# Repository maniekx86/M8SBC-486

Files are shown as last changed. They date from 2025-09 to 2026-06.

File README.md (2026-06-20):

# M8SBC-486

All the sources (Schematics, PCB, VHDL, BIOS sources) for the M8SBC-486. 

This project is a 486 Homebrew computer, with some efforts to make it kinda PC compatible. See [my page about it](https://maniek86.xyz/projects/m8sbc_486.php).

soldered board

## Specs:

- 150*150mm 4 layer PCB
- PGA-168 socket for 5V 486 CPUs.
- Xilinx Spartan II XC2S100 FPGA as "chipset". Codename "Hamster 1"
- 4MB SRAM, (8*HM628512)
- 256KB of ROM (W29C020 or 39SF020A) (224 KB accessible)
- 8254 Programmable Interval Timer
- 8259 Programmable Interrupt Controller
- Two 16-bit ISA slots
- 8042 compatible PS/2 keyboard controller. Implemented in the FPGA
- Simple CMOS RTC and CMOS storage. Implemented in the FPGA too
- ATMega128 as reset circuit handler, nonvolatile CMOS storage and bitstream loader.

The FSB frequency is currently set to a fixed 24 MHz (DX2 CPUs run then at 48 MHz), but this can be changed by uncommenting/commenting lines in the FPGA source.

Secondary PIC and DMA are missing, so the compatibility is not full. The missing DMA especially breaks support for sound cards.

## Current progress:

The hardware and FPGA are mostly done. BIOS is capable of booting DOS. There are a few issues & bugs, but they are being slowly fixed.

Among the most impressive things the board (as time of writing: 20/06/2026) is capable of:

- Running Linux 2.2.26 ([using custom bootloader](https://github.com/maniekx86/linux_m8sbc_boot)) and Linux 4.4.302 (documentation is coming soon)

- Running MS-DOS and FreeDOS: The software compatibility is mixed. Some software hangs the system, throws exceptions, but some run fine. Most notable are: Second Reality demo (no sound), Prince of Persia, Wolfenstein 3D, Fasttracker II (PC speaker works in one mode, LPT DAC works okay), 3DBench 1.0c, CACHECHK. For more software checks and detailed information, see the compatibility table on the [project's website](https://maniek86.xyz/projects/m8sbc_486.php).

- Running DOOM ([FastDOOM](https://github.com/viti95/FastDoom) running on FreeDOS 1.4)

## Hardware diagram

Hardware diagram

<hr>

## Special thanks to [PCBWay](https://www.pcbway.com)!

[](https://www.pcbway.com)

Special thanks to PCBWay for sponsoring PCBs for this project! Their sponsorship was a huge help and enabled me to make progress with this project. PCBWay is a well-known PCB prototyping and manufacturing service, providing high-quality boards and excellent customer support. I have worked with their boards in the past and can say that they are of great quality. I easily placed an order for PCBs on their platform for this project without any problems. The sponsorship also included a free quick delivery option. If you’re looking for reliable PCB prototyping and manufacturing services, I highly recommend [checking them](https://www.pcbway.com).

# Folders

## pcb/

Schematic and PCB design for this homebrew computer. Board is 150mm*150mm with 4 layers. (Placement of the screw holes is not compliant with any standard)

## chipset/

Sources for the "Hamster 1" chipset. FPGA used is XC2S100 (Xilinx Spartan II). Compile with Xilinx ISE 10.1

## avr/

Sources for AVR ATMega128:

Small AVR firmware that configures the FPGA from on-chip flash at power-up and manages system reset for the M8SBC-486 project

## bios/

M8SBC-486 SeaPig BIOS

Based on this project: [b-dmitry1/BIOS](https://github.com/b-dmitry1/BIOS)

## Disclaimer

This project is essentially my hobby, as I like retro, electronics, digital circuits and low-level programming. I never expected this computer to run DOS in the first place. I consider it pretty much experimental and made to research the workings of older x86 chips. I am pretty sure that this work could be used to build something more robust and stable or even to develop fully custom-made boards for other x86 CPUs. It took me a lot of time, but I don't regret it. There are still many issues, but it's heartwarming that I can get so much existing software to work. And, thanks to everyone for support!

## Acknowledgements

Special thanks to: TheRetroWeb community, [b-dmitry1](https://github.com/b-dmitry1) and [PCBWay](https://pcbway.com/)

## More images

PCB bottom
3d render back
pcb view

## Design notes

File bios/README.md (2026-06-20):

# M8SBC-486 SeaPig BIOS

Minimal BIOS for M8SBC-486 that is capable of booting various operating systems such as MS-DOS, FreeDOS or Linux. 

Current version: A2.02

See docs/ for more technical information and release history.

## Building

Requirements: `make`, `nasm`, `dd`, `i686-linux-gnu-gcc`, `python3` (with Pillow installed, required for boot logo)

To build, clone repository and run `make` in this directory. Ready to flash image will be at `out/m8sbc_flash.bin`

## Improvements

- Fancy POST screen
- LBA support (read)
- Hard drive detection
- BIOS setup
- Extended memory test
- Compatibility fixes
- POST codes (see docs/)
- More complete keyboard implementation

## Issues / TODOs

- No LBA write support
- Compact flash cards get randomly corrupted (unsure if it's a hardware or BIOS issue).

## Original README

### x86 embedded BIOS R3

Very compact (less than 8KB of ROM space) x86 BIOS for embedded systems, FPGA, and emulators.

### Implemented functions and features

* Minimal initialization
* Minimal functionality ISRs 10h-1Ah
* Lower memory test with continuous mode to help debugging FPGA SDRAM controller
* Very compact Video BIOS
* Minimal SVGA functionality enough to run hi-res games like "Heroes Of Might and Magic" and "Transport Tycoon"
* Supports add-on ROM chips (see config.inc)
* BIOS disk hypercall for emulators
* SPI mode SD-card support on FPGA boards
* Very simplified USB HID device support for FPGA boards
* Good for a systems without video adapter
* Customizable SPI/USB drivers
* A20 line and PLL control (frequency multiplier for 486)

### Known issues

* No hardware detection / BIOS setup (to save ROM space)
* No extended memory test
* Int 13h (BIOS disk) supports only reset/read/write functions
* Internal video BIOS doesn't support printing text in graphic mode
* Video adapter initialization incomplete so will not work properly with a real VGA chips without OEM BIOS

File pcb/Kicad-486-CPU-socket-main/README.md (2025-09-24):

# KiCad-486-CPU-socket
486 CPU socket library for KiCad 7

## Installation

### Symbol installation
Use the following menu: "Preferences" -> "Manage Symbol Libraries..."
In "Global Libraries" or "Project Specific Libraries" add [486_Socket.kicad_sym](486_Socket.kicad_sym) file

### Footprint installation
Use the following menu: "Preferences" -> "Manage Footprint Libraries..."
In "Global Libraries" or "Project Specific Libraries" add [486_Socket.pretty](486_Socket.pretty) folder
If the 3D view is not working, open the footprint "486Socket", press E key and in "Footprint Properties" window, "3D Models" tab, add [486_Socket.step](486_Socket.step) file. Here you may need to adjust the offset of the 3D model to match the pinout.

## Images
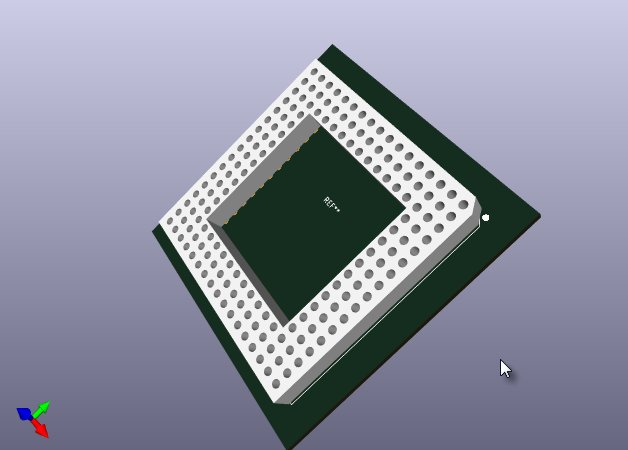
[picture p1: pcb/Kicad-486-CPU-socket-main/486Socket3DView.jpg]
3D view

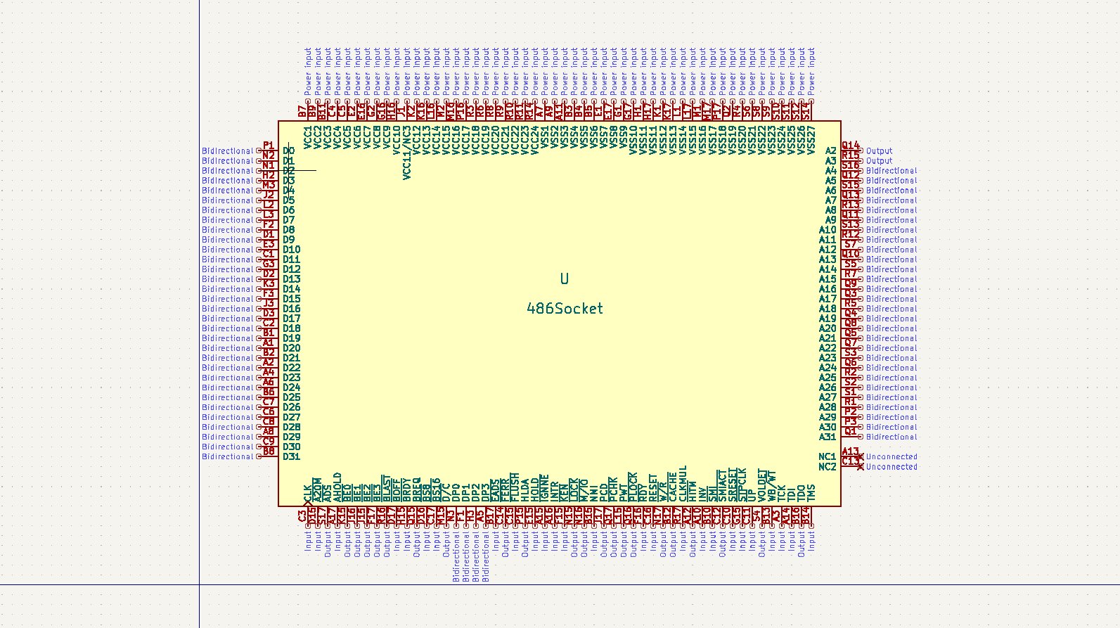
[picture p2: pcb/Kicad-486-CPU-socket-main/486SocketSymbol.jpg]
Symbol

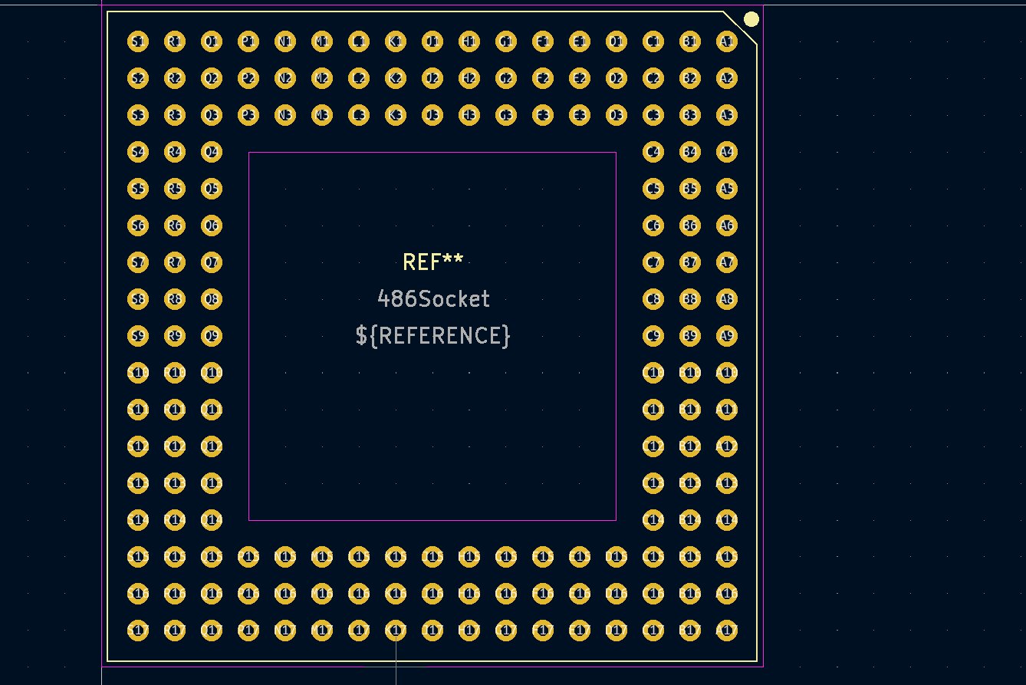
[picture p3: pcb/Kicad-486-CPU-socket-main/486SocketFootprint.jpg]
Footprint


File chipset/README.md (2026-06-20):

# M8SBC-486 FPGA sources

Codename: "Hamster 1" chipset

Experimental "chipset" made for M8SBC-486. 

- 24 MHz max FSB (At current time of writing, might be possible to go further)
- Can address up to a maximum of 4MB of SRAM
- No support for burst data transfers
- Integrated [8042 compatible keyboard controller](https://github.com/maniekx86/kbc_8042_vhdl)
- Integrated simple RTC/CMOS (CMOS volatile)

Full documentation: TO DO. At this time some information available is [here](https://maniek86.xyz/projects/m8sbc_486_hw_chp.php).

## Importing & building

To properly import and build VHDL sources to an FPGA bitstream, you have to:

1. Install Xilinx ISE 10.1. Downloads are still available on the [AMD website](https://www.xilinx.com/support/download/index.html/content/xilinx/en/downloadNav/vivado-design-tools/archive-ise.html). I've used "ISE Design Suite - 10.1  Full Product Installation"

2. Launch Project navigator and create new project (File -> New Project)

3. Choose Project name, Project location. For "Top-level source type" choose HDL. Click next

4. Configure Device Properties:
   
   - Product Category: All
   - Family: Spartan2
   - Device: XC2S100
   - Package: TQ144
   - Speed: Choose depending on your part, if unsure -6 should work for all
   - Synthesis Tool: XST (VHDL/Verilog)
   - Simulator: Leave as is
   - Preferred Language: VHDL
   - Enable enhanced Design Summary:  Yes
   - Enable Message Filtering: No
   - Enable Incremental Messages: No
   
   Click next

5. In "Create New Source" dialog, do not do anything. Click Next

6. In the "Add Existing Sources" dialog, click Add Source, navigate to the directory where you downloaded the VHDL sources and select all (including the .ucf file). Leave "Copy to Project" checked. Click Next and then Finish

7. You will see the "Adding Source Files" dialog box. Each source should have a green check mark. Do not change anything here; click OK. If everything went right, you should see in the Sources window (left top) all the sources with the m8sbc_main.vhd being at top.

8. In Processes window (below the Sources window), double click on the "Generate Programming File". If the process finishes successfully then the .bit file should be located in the project's directory.

### Issues with ISE 10.1

I successfully got the ISE 10.1 to work pretty nicely on the Windows 10 x64, however, it is possible you will run into problems during install or compilation. Below are potential issues:

#### During compilation there is error "Failed to link the design"

See: [Error in VHDL (Xilinx): failed to link the design - Stack Overflow](https://stackoverflow.com/questions/23033297/error-in-vhdl-xilinx-failed-to-link-the-design)

## What's next

To "flash" the bitstream to the M8SBC-486, copy the .bit file to the AVR sources directory and compile it. The bitstream will be embedded into ATMega128, and will be loaded on every power up by it. You can alternatively load up the bitstream temporarily to the FPGA using the onboard JTAG connector.

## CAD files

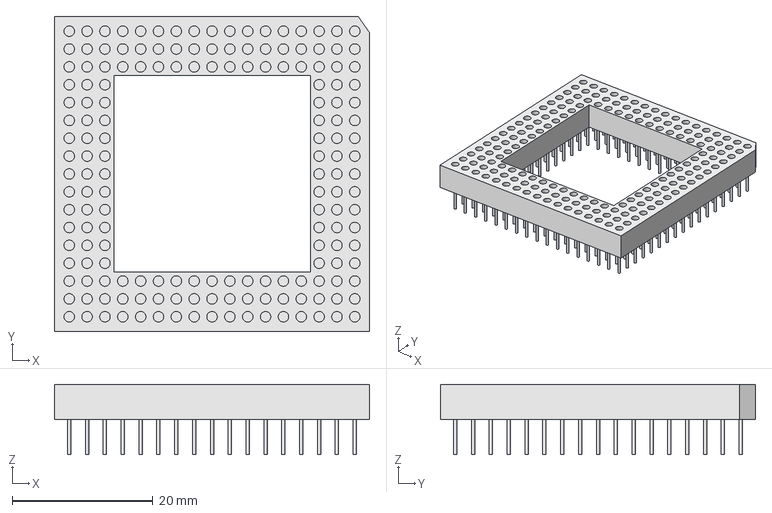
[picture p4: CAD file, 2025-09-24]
pcb/Kicad-486-CPU-socket-main/486_Socket.step
44.8 x 44.8 x 10.0 mm

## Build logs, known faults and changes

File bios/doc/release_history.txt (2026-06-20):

M8SBC-486 SeaPig BIOS release history

Current known BIOS issues:
  - No LBA write support
  - Compact flash cards get randomly corrupted (unsure if it's a hardware or BIOS issue).

A2.02:
  Notes:
    - Requires chipset version 0003 (keyboard controller rewrite, way better 8042 compatibility)
  Changes / fixes:
    - Major extension BIOS ROM caller bug fix: better graphics card compatibility
    - Major keyboard driver update: Caps lock, Num lock and Scroll lock support, PS/2 two way communication. 
    - IDE driver fixes and optimizations (flash cards writes are still broken)

A2.01:
  Changes / fixes:
    - Added a POST summary after the main POST screen
    - Added proper POST codes
    - Added real mode exception handler
    - Added fixed pointer for INT15. This fixes QEMM compatibility
    - IDE detection fixes
    - Memory test error message update
    - Version display in setup

A2.00:
  First release based on BIOS by b-dmitry1

  Improvements over base BIOS:
    - Fancy POST screen
    - LBA support (read)
    - Hard drive detection
    - BIOS setup
    - Extended memory test
    - Compatibility fixes
  Known issues:
    - No LBA write support
    - Compact flash cards get randomly corrupted (unsure if it's a hardware or BIOS issue).

1.00:
  First testing BIOS, abandoned

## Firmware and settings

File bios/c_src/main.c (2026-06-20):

#include <stdint.h>
#include "x86io.h"          // IN(), OUT(), INW(), OUTW()
#include "interrupts.h"     // IDT, PIC, IRQ ISRs
#include "utils.h"          // C utility functions (strings, memory)
#include "keyboard.h"       // Onboard compatible 8042 PS/2 controller functions
#include "vga.h"            // VGA print, VGA text mode logo
#include "cpudetect.h"      // CPUID parse, Cyrix check, FPU check
#include "ide.h"            // IDE functions and detection
#include "cmos.h"           // CMOS settings read, write, restore, save

#include "about.h"
#include "setup.h"

#ifndef VERSION
#define VERSION "?.??"
#endif

#define POST(x) outb(0x80, x)

volatile uint32_t *cpuid_edx = (uint32_t*)0x5F0;  // DX from reset is stored to 0x5F0 by ASM
// volatile uint16_t *bda_warm_boot = (uint16_t*)0x472; // Warm boot flag. If set to 0x1234, skip some checks. Needs fixes in real mode asm, so TODO

// Global variables
uint16_t cpuid;
int cyrix_cpu = 0;
char cpu_model[48];
int fpu_present = 0;

int mem_total = 64;             // base 64K already tested
int ide_detected = 0;
char ide_name[48];
int skip_memory_test = 0;
uint8_t cmos_status;

// Memory test regions:
// 0x0010000 - 0x009FFFF: start: 0x0010000, 9 blocks
// 0x0100000 - 0x03FFFFF: start: 0x0100000, 48 blocks
// 0x04A0000 - 0x04FFFFF: start: 0x04A0000, 6 blocks
// block is 64K in size
//
// Base 64K was already tested before and it should 
// be working if we already hit this point

#define MEMTEST_REGIONS_TOTAL 3
struct memtest_regions_struct {
    uint32_t offset;
    uint8_t blocks_64k;
} memtest_regions[MEMTEST_REGIONS_TOTAL] = {
    {0x0010000, 9},
    {0x0100000, 48},
    {0x04A0000, 6}
};

void memory_error(uint32_t read, uint32_t expected, uint32_t location, int x_pos) { // TO UPDATE/IMPROVE
    char buf[16];
    
    POST(0xE1); // E1 - Extended memory test failed
    
    skip_memory_test = 0; // Clear if already selected
    
    location = location * 4;
    
    // FAIL: [address] - [read]: [value] [expected]: [value]
    // example: FAIL: DEADBEEF - R: 12121212 E: 55AA55AA
    vga_print_string("FAIL: ", x_pos, 10, 0x0C);
    itoapad(location, buf, 16, 8);
    vga_print_string(buf, x_pos + 6, 10, 0x0C); // x 14
    vga_print_string("- R:", x_pos + 15, 10, 0x0C); // x 20
    itoapad(read, buf, 16, 8);
    vga_print_string(buf, x_pos + 20, 10, 0x0C); // x 28
    vga_print_string("E: ", x_pos + 29, 10, 0x0C); // x 32
    itoapad(expected, buf, 16, 8);
    vga_print_string(buf, x_pos + 32, 10, 0x0C); 
    vga_print_string("Press ESC to ignore", x_pos, 11, 0x0C);
    
    while(skip_memory_test==0) asm("nop");
}

__attribute__ ((optimize(2))) void memory_test(int quick) {
    volatile uint32_t *memory = (volatile uint32_t *)0x00000000;
    
    // At this point cache is already ON but we gonna invalidate it after writes

    mem_total = 64; // base 64k already tested
    char print_buf[20];
    int inc_amount;
    int print_len = 0;

    if(quick) {
        inc_amount = 32; 
    } else {
        inc_amount = 1;
    }

    for(int region=0; region < MEMTEST_REGIONS_TOTAL; region++) {
        // 0x0010000
        uint32_t mem_offset = memtest_regions[region].offset / 4;
        uint8_t blocks = memtest_regions[region].blocks_64k;

        for(int block=0; block < blocks; block++) {

            uint32_t ticks_next = irq0_ticks + 5; // Slow down

            for(uint32_t wpos = 0; wpos < (0x10000/4); wpos+=inc_amount) { // uint32_t align is 4 so 1 offset = 4 bytes
                volatile uint32_t *current_ptr = memory + mem_offset + wpos;
                *current_ptr = 0x55AA55AA;
            }
            asm volatile("wbinvd");
            for(uint32_t rpos = 0; rpos < (0x10000/4); rpos+=inc_amount) {
                volatile uint32_t *current_ptr = memory + mem_offset + rpos;
                if(*current_ptr != 0x55AA55AA) {
                    // ERROR
                    memory_error(*current_ptr, 0x55AA55AA, mem_offset + rpos, 20 + print_len + 1);
                    return;
                }
            }
            // Swap bits
            for(uint32_t wpos = 0; wpos < (0x10000/4); wpos+=inc_amount) {
                volatile uint32_t *current_ptr = memory + mem_offset + wpos;
                *current_ptr = 0xAA55AA55;
            }
            asm volatile("wbinvd");
            for(uint32_t rpos = 0; rpos < (0x10000/4); rpos+=inc_amount) {
                volatile uint32_t *current_ptr = memory + mem_offset + rpos;
                if(*current_ptr != 0xAA55AA55) {
                    // ERROR
                    memory_error(*current_ptr, 0xAA55AA55, mem_offset + rpos, 20 + print_len + 1);
                    return;
                }
            }
            // if mem test goes too fast, slow down by counting ticks
            while(ticks_next > irq0_ticks) { asm("nop"); }

            mem_total += 64;
            mem_offset = mem_offset + 0x4000; // 0x10000 / 4
            //vga_print_itoa(tested_memory_k, 20, 10, 0x0F, 10, 0);

            if(skip_memory_test==1) {
                mem_total = 4096;
            }
            
            itoa(mem_total, print_buf, 10);
            if(quick) {
                strcat(print_buf, " KB (q)");
            } else {
                strcat(print_buf, " KB");
            }
            vga_print_string(print_buf, 20, 10, 0x0F);
            print_len = strlen(print_buf);
            
            if(skip_memory_test==1) break;
            
        }
        
    }

}

enum POST_action_enum {
    POST_NORMAL,
    POST_SETTINGS,
    POST_SYSTEM_TEST,
    POST_ABOUT
} POST_action;

void POST_kb_handle() {
    // kb buffer should be always not empty when this routine is executed
    // Future TODO - work on translated keys instead of working with raw keys
    uint8_t scancode = kb_get_scancode();

    switch (scancode) {

        case 0x01: // ESC
            skip_memory_test = 1;
            break;
        
        default:
            break;
    }

    if(POST_action == POST_NORMAL) {
        switch (scancode) {

            case 0x3B: // F1
                POST_action = POST_SETTINGS;
                for(int x=0; x<80; x++) {
                    vga_print_char(' ', x, 24, 0x07);
                }
                vga_print_string("Selected: SETTINGS", 1, 24, 0x0F);
                break;

            case 0x3C: // F2
                break; // to do in future
                POST_action = POST_SYSTEM_TEST;
                for(int x=0; x<80; x++) {
                    vga_print_char(' ', x, 24, 0x07);
                }
                vga_print_string("Selected: SYSTEM TEST", 1, 24, 0x0F);
                break;
        
            case 0x3D: // F3
                POST_action = POST_ABOUT;
                for(int x=0; x<80; x++) {
                    vga_print_char(' ', x, 24, 0x07);
                }
                vga_print_string("Selected: ABOUT", 1, 24, 0x0F);
                break;

            default:
                break;
        }
    }
}

void main() {
    // Interrupts are disabled
    POST(0x80); // 80 - C main() running. IDT init
    
    idt_init(); // Remaps and masks all IRQ internally ( pic_remap(0x20); pic_set_mask(0xFF); )
    
    POST(0x81); // 81 - CMOS read

    cmos_status = cmos_read();
    
    POST(0x82); // 82 - CPU identification
    fpu_present = is_fpu_present();
    cyrix_cpu = is_cyrix_cpu();

    cpuid = (uint16_t)(*cpuid_edx & 0xFFFF);
    detect_486_model(cpuid, cyrix_cpu, cpu_model, 0);

    POST(0x83); // 83 - PIT setup and test
    
    // 100 Hz and enable PIT IRQ
    pit_set_int_freq(100);
    pic_enable_irq(0);
    
    sti();
    while(1) { // Verify that interrupts work
        if(irq0_ticks>3) break;
        asm volatile("nop");
        // If this loop never exits, verify PIT and PIC, TODO: timeout and error message
    }
    
    POST(0x84); // 84 - Keyboard initialization and test
    
    kb_init();

    POST_action = POST_NORMAL;
    kb_set_callback(POST_kb_handle);

    cli();

    // Draw BIOS
    
    POST(0x85); // 85 - BIOS POST display init

    vga_load_logo(); 
    vga_draw_logo(60, 1);
    vga_draw_extra_logo(1,1);
    vga_draw_extra_logo(1,2);
    
    POST(0x86); // 86 - BIOS POST display

    vga_print_string("SeaPig 486 Single Board Computer BIOS " VERSION , 4, 1, 0x07);
    vga_print_string("Copyright (C) 2024-2026, maniek86.xyz", 4, 2, 0x07);
    vga_print_string("M8SBC-486 REV 1.0 BIOS (DEV)", 1, 4, 0x07);

    vga_print_string("Main Processor :", 3, 7, 0x07);
    vga_print_string("FPU Present :", 6, 8, 0x07);
    vga_print_string("Memory Test :", 6, 10, 0x07);

    vga_print_string("---- Built " __DATE__ " " __TIME__ " / CHP V1 / Derived from BIOS by b-dmitry1 ----", 1, 23, 0x07);

    /*
    vga_print_string("[ESC SKIP MEMORY TEST]  [F1 SETTINGS]  [F2 SYSTEM TEST]  [F3 ABOUT]", 7, 24, 0x0A);
    // highlight ESC, F1, F2, F3
    vga_set_char_attr(0x0F, 7+1, 24);
    vga_set_char_attr(0x0F, 7+2, 24);
    vga_set_char_attr(0x0F, 7+3, 24);
    
    vga_set_char_attr(0x0F, 7+25, 24);
    vga_set_char_attr(0x0F, 7+26, 24);
    vga_set_char_attr(0x0F, 7+40, 24);
    vga_set_char_attr(0x0F, 7+41, 24);
    vga_set_char_attr(0x0F, 7+58, 24);
    vga_set_char_attr(0x0F, 7+59, 24);
    */

    vga_print_string("[ESC SKIP MEMORY TEST]  [F1 SETTINGS]  [F3 ABOUT]", 15, 24, 0x0A);
    // highlight ESC, F1, F3
    vga_set_char_attr(0x0F, 15+1, 24);
    vga_set_char_attr(0x0F, 15+2, 24);
    vga_set_char_attr(0x0F, 15+3, 24);
    
    vga_set_char_attr(0x0F, 15+25, 24);
    vga_set_char_attr(0x0F, 15+26, 24);
    vga_set_char_attr(0x0F, 15+40, 24);
    vga_set_char_attr(0x0F, 15+41, 24);

    vga_print_string(cpu_model, 20, 7, 0x0F);

    if(fpu_present) {
        vga_print_string("Yes", 20, 8, 0x0F);
    } else {
        vga_print_string("No", 20, 8, 0x0F);
    }

    if(cmos_status==0) { // cmos was invalid
        vga_print_string("CMOS checksum was invalid! Cleared", 23, 22, 0x04);
    }
    
    sti();
    
    POST(0x87); // 87 - Extended memory test
    
    // if(bda_warm_boot==0x1234) { // Warm boot. needs fixes in real mode asm, so TODO
    //   skip_memory_test = 1;
    // }

    memory_test(cmos_get(CMOS_QUICK_MEMTEST));
    
    POST(0x88); // 88 - Primary IDE detection

    vga_print_string("Primary IDE : detecting...", 6, 12, 0x07);

    IDE_reset();

    if(IDE_wait_busy(500) && IDE_detect(ide_name)) { // wait 5 seconds
        ide_name[42] = 0;
        ide_detected = 1;
        vga_print_string("              ", 20, 12, 0x0F);
        vga_print_string(ide_name, 20, 12, 0x0F);
    } else {
        vga_print_string("None          ", 20, 12, 0x0F);
        strcpy(ide_name, "None");
        ide_detected = 0;
    }
    
    POST(0x89); // 89 - POST display wait

    kb_set_callback(NULL);

    uint32_t boot_delay;

    if(ide_detected == 0) {
        POST_action = POST_SETTINGS;
    }

    switch(POST_action) {
        case POST_ABOUT:
            boot_delay = irq0_ticks + 10;
            POST(0xA0); // A0 - About display
            about_display();
            break;

        case POST_SETTINGS:
            POST(0xA1); // A1 - BIOS setup
            boot_delay = irq0_ticks + 10;
            setup_display(cpuid, cyrix_cpu, mem_total, fpu_present, ide_name, ide_detected);
            break;

        default:
            boot_delay = irq0_ticks + 100;
            break;
    }


    while(1) {
        if(irq0_ticks>boot_delay) {
            break;
        }
        asm volatile("nop");
    }


    if(cmos_get(CMOS_LOCK_CMOS)) cmos_lock();
    
    POST(0x8A); // 8A - Restore PIC
    
    cli(); // Reset PIC to default
    pic_remap(8); 
    pic_set_mask(0x00); 
    idt_restore_real_mode();
    
    POST(0x8B); // 8B - Restore VGA and print summary

    vga_restore_font();
    vga_clear(0x07);
    
    for(int x=0; x<80; x++) {
        vga_print_char('=', x, 0, 0x07);
        vga_print_char('=', x, 4, 0x07);
    }
    vga_print_string(" SeaPig BIOS ", 32, 0, 0x07);
    
    vga_print_string("Processor", 1, 1, 0x07);
    vga_print_char(':', 13, 1, 0x07); 
    vga_print_string("Memory", 1, 2, 0x07);
    vga_print_char(':', 13, 2, 0x07);
    vga_print_string("Primary IDE", 1, 3, 0x07);
    vga_print_char(':', 13, 3, 0x07);
    
    vga_print_string(cpu_model, 15, 1, 0x07);
    int mem_str_len = vga_print_itoa(mem_total, 15, 2, 0x07, 10, 0);
    vga_print_string("KB", 16+mem_str_len, 2, 0x07);
    vga_print_string(ide_name, 15, 3, 0x07);
    
    // OS text should be printed at Y=6
    
    
    // Cursor gets moved by real mode section

    return;
}

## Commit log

2025-09-24 Add KiCad project (first rev)
    [486_Socket.step, cpu.kicad_sch, fpga.kicad_sch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]
2025-09-24 Update PCB (fix vias) and update date on schematic
    [cpu.kicad_sch, fpga.kicad_sch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]
